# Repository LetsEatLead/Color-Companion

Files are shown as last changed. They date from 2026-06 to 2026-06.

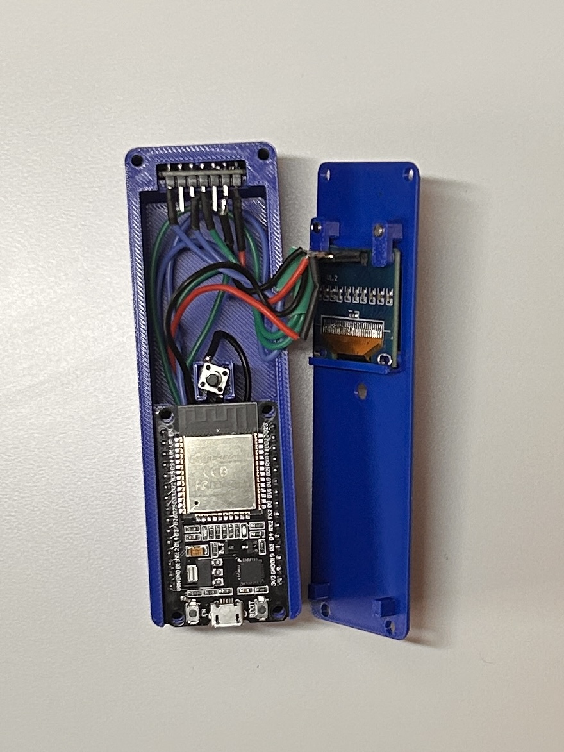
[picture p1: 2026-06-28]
Media/Internals.JPEG

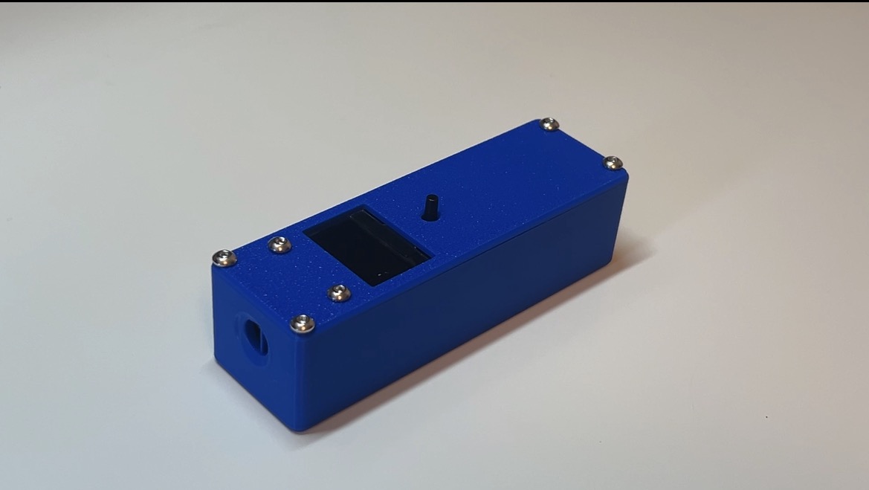
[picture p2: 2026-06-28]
Media/First Image.JPEG

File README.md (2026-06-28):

# Color-Companion


Ever seen a color and thought, I want that color! The Color Companion is a handheld device with a color sensor and display, which can give you the exact RGB and HEX values of anything for you!

Its built using a esp32 devboard, a ssd1306 oled display, and a TCS34725 color sensor. The code uses Adafruits libraries for communication between the display and sensor over i2c. 

# Demo Video

https://github.com/user-attachments/assets/e2945326-af05-4202-8325-9a9cc32651e1

# Wiring

ESP32 ground --> sensor ground + display ground + button  

ESP32 5v --> sensor vin + display vcc (Make sure your components are 5v tolerant!)   

ESP32 GPIO 23 --> button  

ESP32 GPIO 22 --> sensor scl + display scl  

ESP32 GPIO 21 --> sensor sda + display sda  

ESP32 GPIO 19 --> sensor led



# 3D printing notes  

Standard settings work fine (I used PLA, 2 walls, 0.2mm layer height)
Please note, this should ideally be printed in black to avoid color contamination for the sensor. If you print in a different color please blackout the sensor shroud using marker or paint.

# Assembly 
Wire together all components (Ideally with soldered connections)  
Place ESP32, button, and sensor in their respective sockets in the main case  
Slide OLED display under hook in top case and secure with two mounting brackets  
Place the top over the main case and screw in the four corners. 


# Bill of Materials  
3D printed parts:  
1x Case Top  
1x Main Case  
2x Display Mounting Bracket  

Components:  
1x Generic ESP32 Devboard  
1x ssd1306 0.96in OLED display  
1x TCS34725 Color Sensor Devboard (Get the one seen in the wiring diagram) 
1x 6x6x12mm pushbutton  
Wires for wiring  
4x M3 12mm screws  
4x M3 6mm screws 
(You can use differently sized M3 screws, just consult the CAD to see if they fit.) 

# Links  
Onshape CAD
https://cad.onshape.com/documents/70483fd3f9557aaf4b7bc699/w/9afb3eae3ce6437ed4a82568/e/d381e982bd1c6c0bcb748ca7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

# AI Disclosure
AI was rarely used for bugfixing, nothing else.

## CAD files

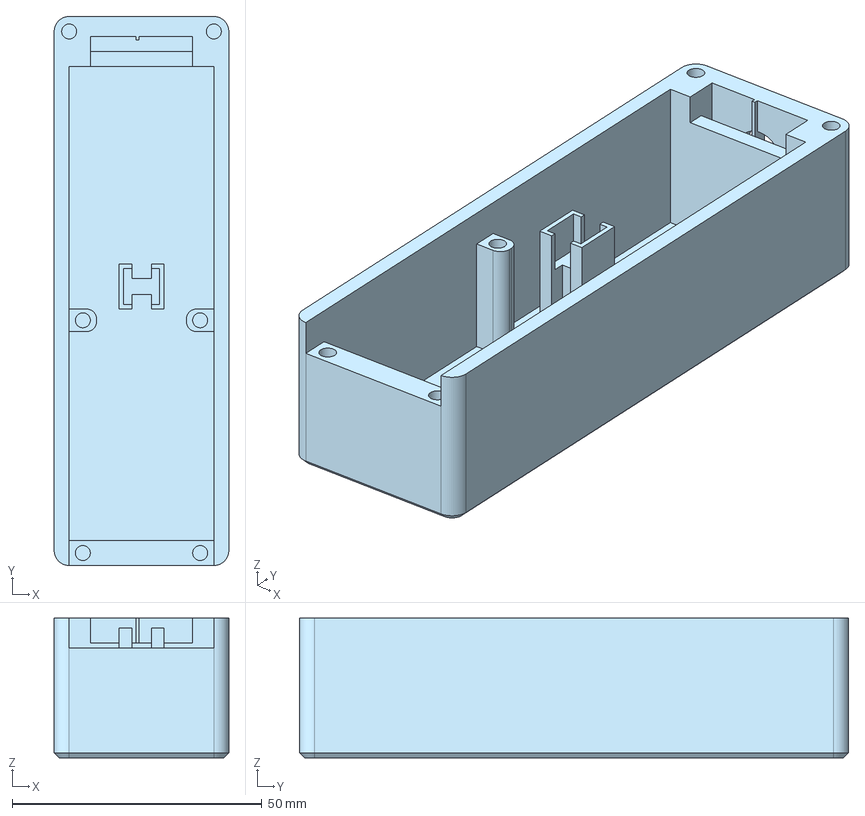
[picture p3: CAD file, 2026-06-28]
3D Files/Main Case.step
35.0 x 110.0 x 28.0 mm

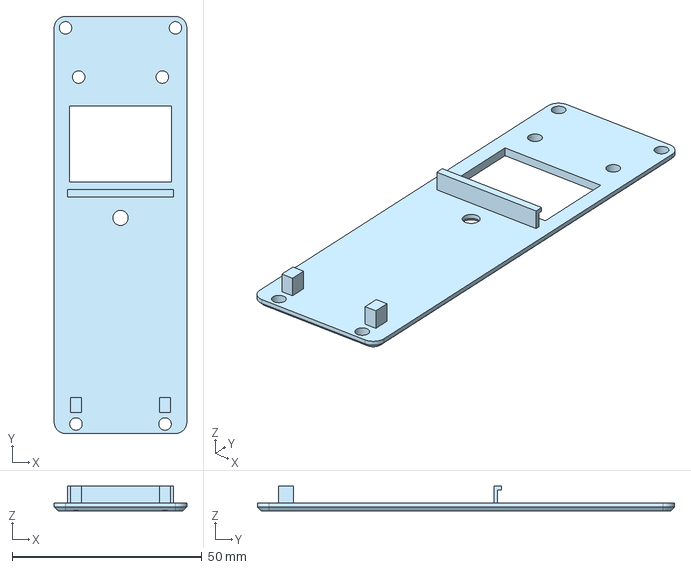
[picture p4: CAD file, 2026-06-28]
3D Files/Case Top.step
35.0 x 110.0 x 6.50 mm

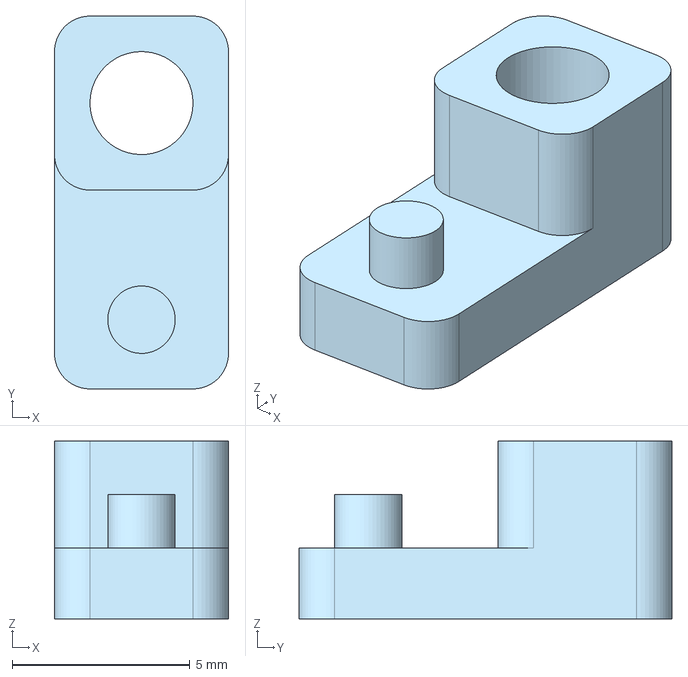
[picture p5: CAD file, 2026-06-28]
3D Files/Display Mounting Bracket.step
4.90 x 10.5 x 5.00 mm

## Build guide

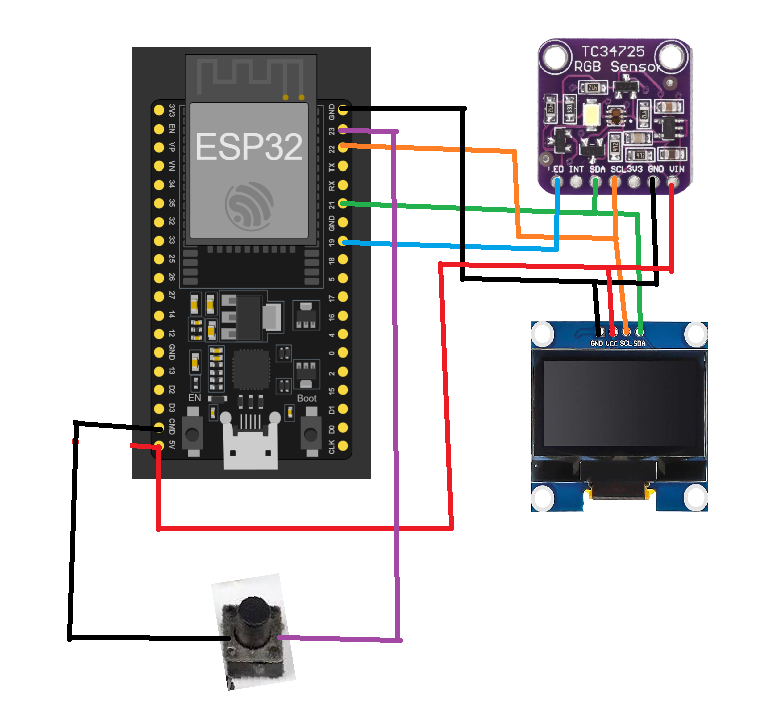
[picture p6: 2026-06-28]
Media/Wiring Diagram.png

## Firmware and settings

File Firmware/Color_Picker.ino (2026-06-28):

#include <Wire.h>
#include <Adafruit_TCS34725.h>
#include <Adafruit_SSD1306.h>
#include <splash.h>

#define SCREEN_WIDTH 128 
#define SCREEN_HEIGHT 64 
#define OLED_RESET     -1 
#define SCREEN_ADDRESS 0x3C 

Adafruit_SSD1306 display(SCREEN_WIDTH, SCREEN_HEIGHT, &Wire, OLED_RESET);
Adafruit_TCS34725 tcs = Adafruit_TCS34725(TCS34725_INTEGRATIONTIME_614MS, TCS34725_GAIN_1X);

int PauseButton = 23;
int SensorLight = 19;

void setup() {
  //Begins serial and displays splash screen
  Serial.begin(115200);
  pinMode(PauseButton, INPUT_PULLUP);
  pinMode(SensorLight, OUTPUT);

  
  delay(500);
  display.begin(SSD1306_SWITCHCAPVCC, 0x3C);
  display.clearDisplay();
  display.setTextColor(WHITE);
  display.setCursor(10,12);
  display.setTextSize(1);
  display.println("Color Companion V1");
  display.setCursor(13, 24);
  display.println("Awaiting Input...");
  display.display();
  display.clearDisplay();
}

void loop() {

    while (digitalRead(PauseButton)) {
    //Stop display refresh and turn off LED
    digitalWrite(SensorLight, LOW);
  }

  //Setting Up Variables and pins before display loop
  char ColorHex[8];
  float red, green, blue;
  tcs.getRGB(&red, &green, &blue);
  int red_I = (int)red;
  int blue_I = (int)blue;
  int green_I = (int)green;
  digitalWrite(SensorLight, HIGH);
  sprintf(ColorHex, "#%02x%02x%02x", red_I, green_I, blue_I);

  // Display Text Loop
  display.clearDisplay();
  display.setCursor(0,0);
  display.setTextSize(2);
  display.println("R: ");
  display.setCursor(36,0);
  display.println(red_I);

  display.setCursor(0,16);
  display.setTextSize(2);
  display.println("G: ");
  display.setCursor(36,16);
  display.println(green_I);

  display.setCursor(0,32);
  display.setTextSize(2);
  display.println("B: ");
  display.setCursor(36,32);
  display.println(blue_I);

  display.setTextSize(2);
  display.setCursor(0,48);
  display.println(ColorHex);
  
  display.display();


}

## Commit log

2026-06-28 Rename Case Top Final.step to Case Top.step
    [Case Top.step]
2026-06-28 Rename Display Mounting Bracket Final.step to Display Mounting Bracket.step
    [Display Mounting Bracket.step]
2026-06-28 Rename Main Case Final.step to Main Case.step
    [Main Case.step]
2026-06-28 Rename Screenshot 2026-06-28 162254.png to Wiring Diagram.png
